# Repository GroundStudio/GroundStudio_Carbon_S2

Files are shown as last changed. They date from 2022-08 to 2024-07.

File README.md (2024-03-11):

GroundStudio Carbon S2
====================================
Carbon S2 cropat la 150 h (https://ardushop.ro/ro/home/2063-placa-de-dezvoltare-carbon-s2.html)

Get it from [ardushop.ro](https://ardushop.ro/ro/home/2063-placa-de-dezvoltare-carbon-s2.html)

Explore all the GroundStudio products at [GroundStudio.ro](https://groundstudio.ro/)

Description
-------------------
Features highly integrated ESP32-S2 with 2.4 GHz WiFi, 4MB Flash, 320kB SRAM, 128kB ROM, 18 GPIO, 10 ADC, 8 touch sensitive pins, 2 UART, I²C 3V3 adapter, RGB smart LED and 1 cell LiPo/LiIon battery charger with optional battery connector.

Contents
-------------------

* [/Documentation](https://github.com/GroundStudio/GroundStudio_Carbon_S2/tree/main/Documentation) -- Pinout.
* [/Hardware](https://github.com/GroundStudio/GroundStudio_Carbon_S2/tree/main/Hardware) -- Schematics, layout.

Versions
-------------------
*(Not all tags shown)*

* [REV0.0.2]
  * changed GPIO3 with GPIO12 between R3 and R8 because GPIO12 cannot be pulled high while in flash mode
  * added 100nF in parallel with R7 for better battery voltage level reading
  * modified the i2c connector label for better visibility
  * adjusted the position of the solder-jumper labels
  * increased the copper fill area under the uC for better cooling

License
-------------------

This is released under the [Attribution-ShareAlike 4.0 International (CC BY-SA 4.0)](https://creativecommons.org/licenses/by-sa/4.0/) license. 
**You are welcome to use this for commercial purposes.**

Please consider contributing back to this project or others to help the open-source hardware community continue to thrive and grow! 

Certifications:

[Open Source Hardware Association](https://certification.oshwa.org/ro000008.html)   
   
certification-mark-RO000008-wide (https://certification.oshwa.org/ro000008.html)

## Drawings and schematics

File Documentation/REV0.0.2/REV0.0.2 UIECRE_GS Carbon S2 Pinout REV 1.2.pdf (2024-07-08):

# GroundStudio Carbon S2

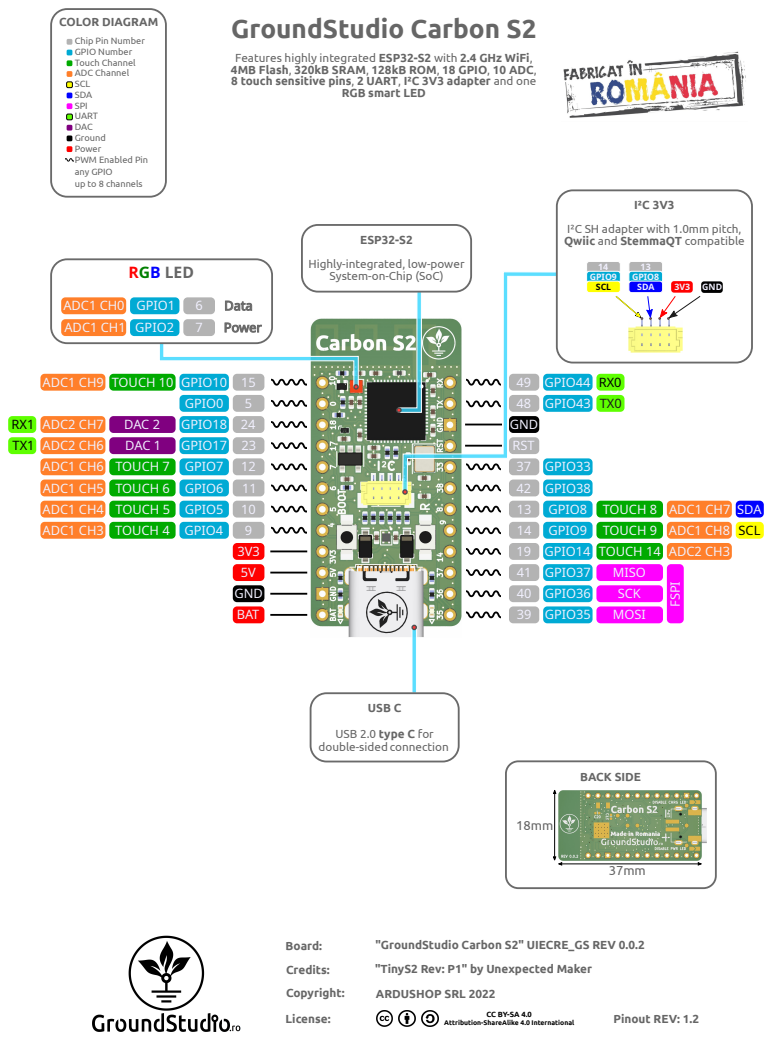
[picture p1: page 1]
COLOR DIAGRAM; ESP32-S2; BACK SIDE; I²C 3V3; GPIO9; GND; GPIO8; SCL; SDA; USB C; GND RST; GPIO38; GPIO8 GPIO9 GPIO14 GPIO37 GPIO36 GPIO35; MISO SCK MOSI; 37 GPIO33; 48 GPIO43; 49 GPIO44; TOUCH 8 TOUCH 9 TOUCH 14; ADC1 CH7 ADC1 CH8 ADC2 CH3; GND BAT; DAC 1 TOUCH 7 TOUCH 6 TOUCH 5; DAC 2; TOUCH 4; GPIO17 GPIO7 GPIO6 GPIO5; GPIO18; GPIO0; GPIO4; GPIO10; ADC2 CH7 ADC2 CH6 ADC1 CH6 ADC1 CH5 ADC1 CH4 ADC1 CH3; ADC1 CH9 TOUCH 10; RGB LED; Data Power; ADC1 CH0 GPIO1 6; ADC1 CH1 GPIO2; Copyright: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

Chip Pin Number
GPIO Number
Touch Channel
ADC Channel
SCL
SDA
SPI
UART
DAC
Ground
Power
PWM Enabled Pin
any GPIO
up to 8 channels

Features highly integrated ESP32-S2 with 2.4 GHz WiFi,
4MB Flash, 320kB SRAM, 128kB ROM, 18 GPIO, 10 ADC,
8 touch sensitive pins, 2 UART, I²C 3V3 adapter and one

RGB smart LED

I²C SH adapter with 1.0mm pitch,
Qwiic and StemmaQT compatible

Highly-integrated, low-power
System-on-Chip (SoC)

USB 2.0 type C for
double-sided connection

"GroundStudio Carbon S2" UIECRE_GS REV 0.0.2

Attribution-ShareAlike 4.0 International

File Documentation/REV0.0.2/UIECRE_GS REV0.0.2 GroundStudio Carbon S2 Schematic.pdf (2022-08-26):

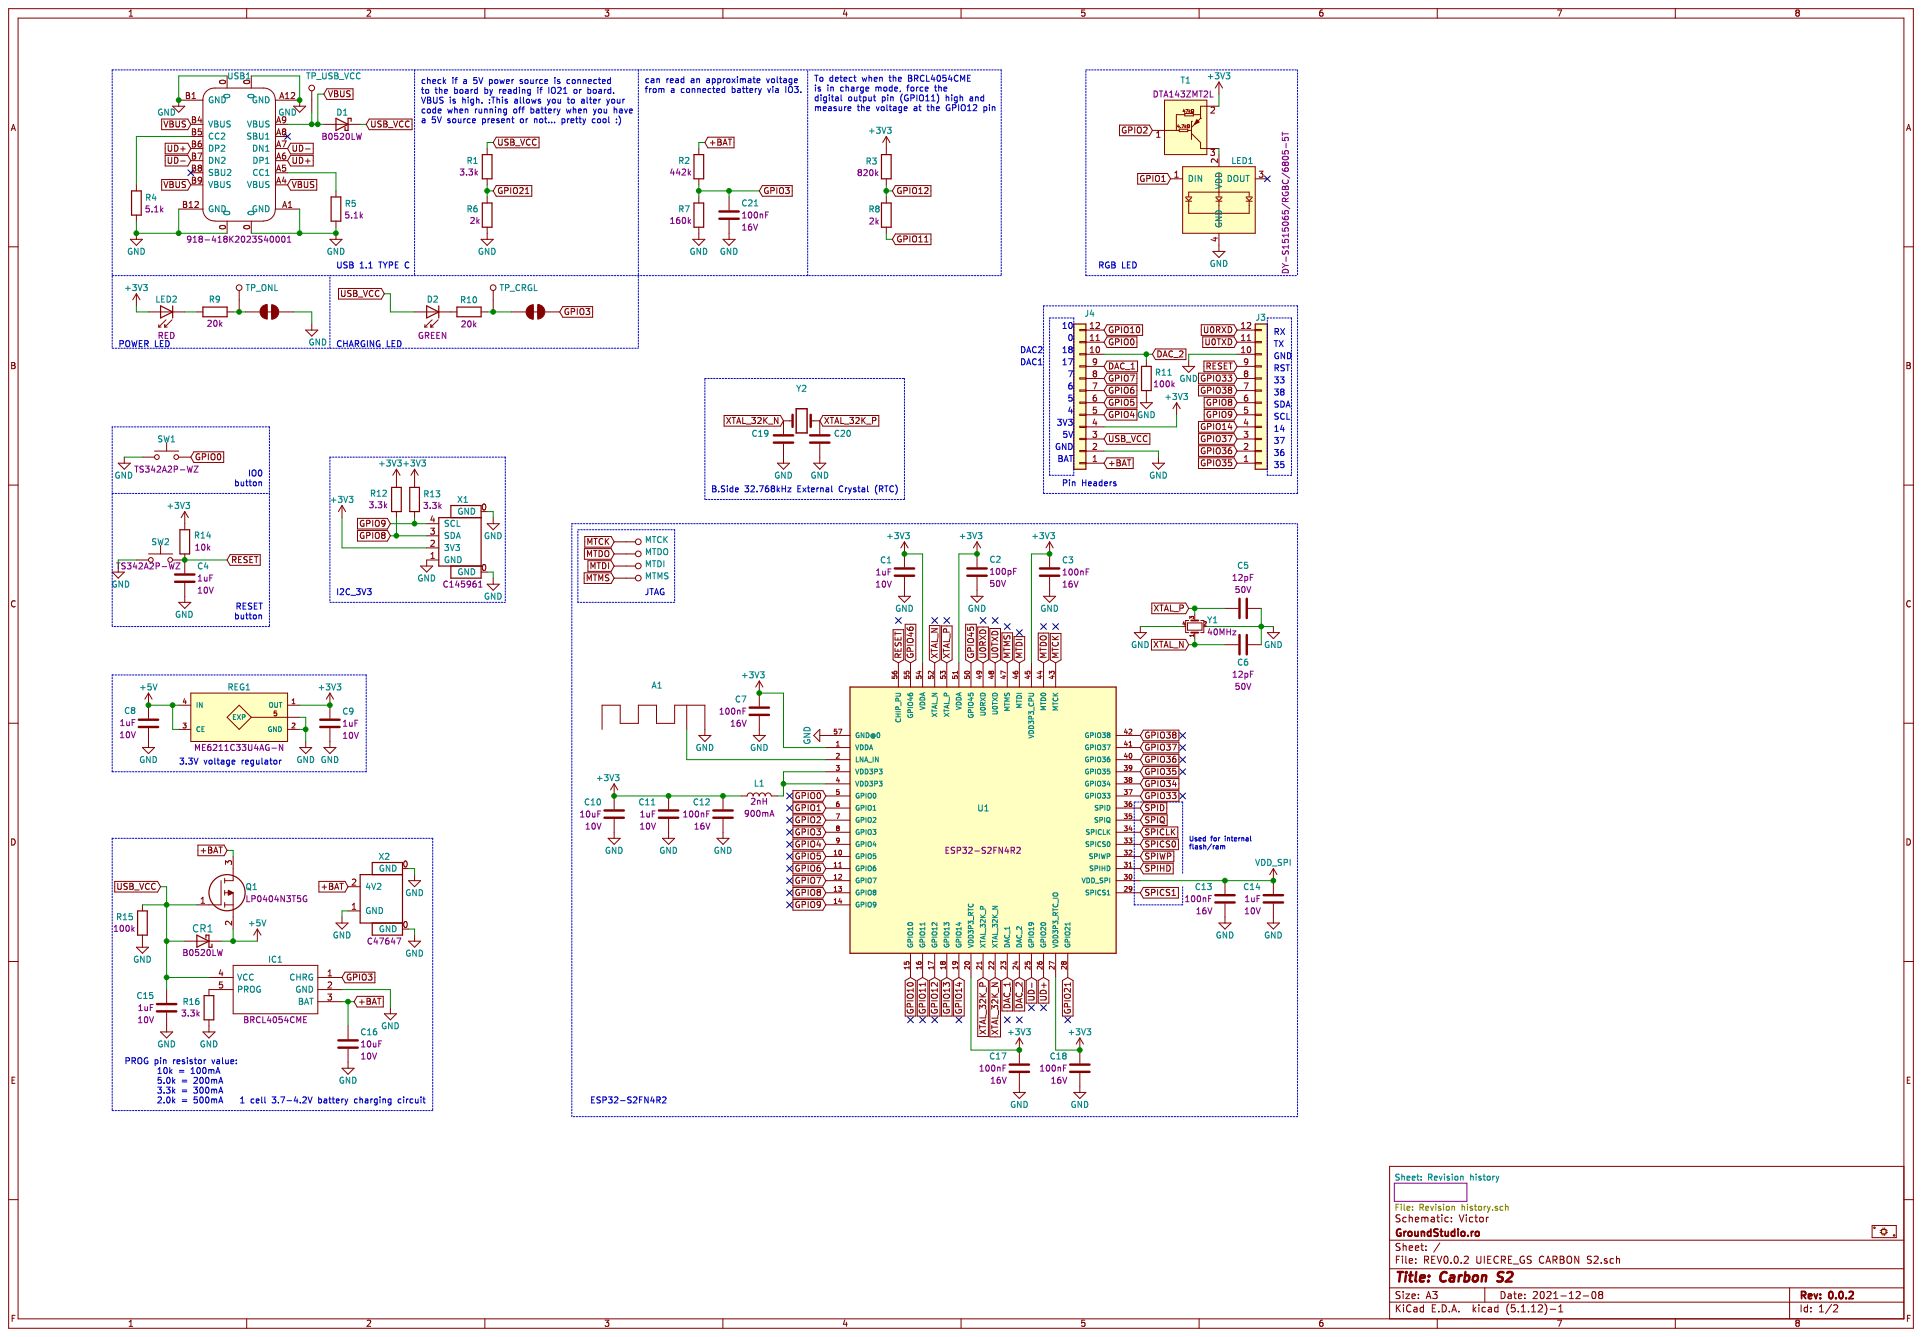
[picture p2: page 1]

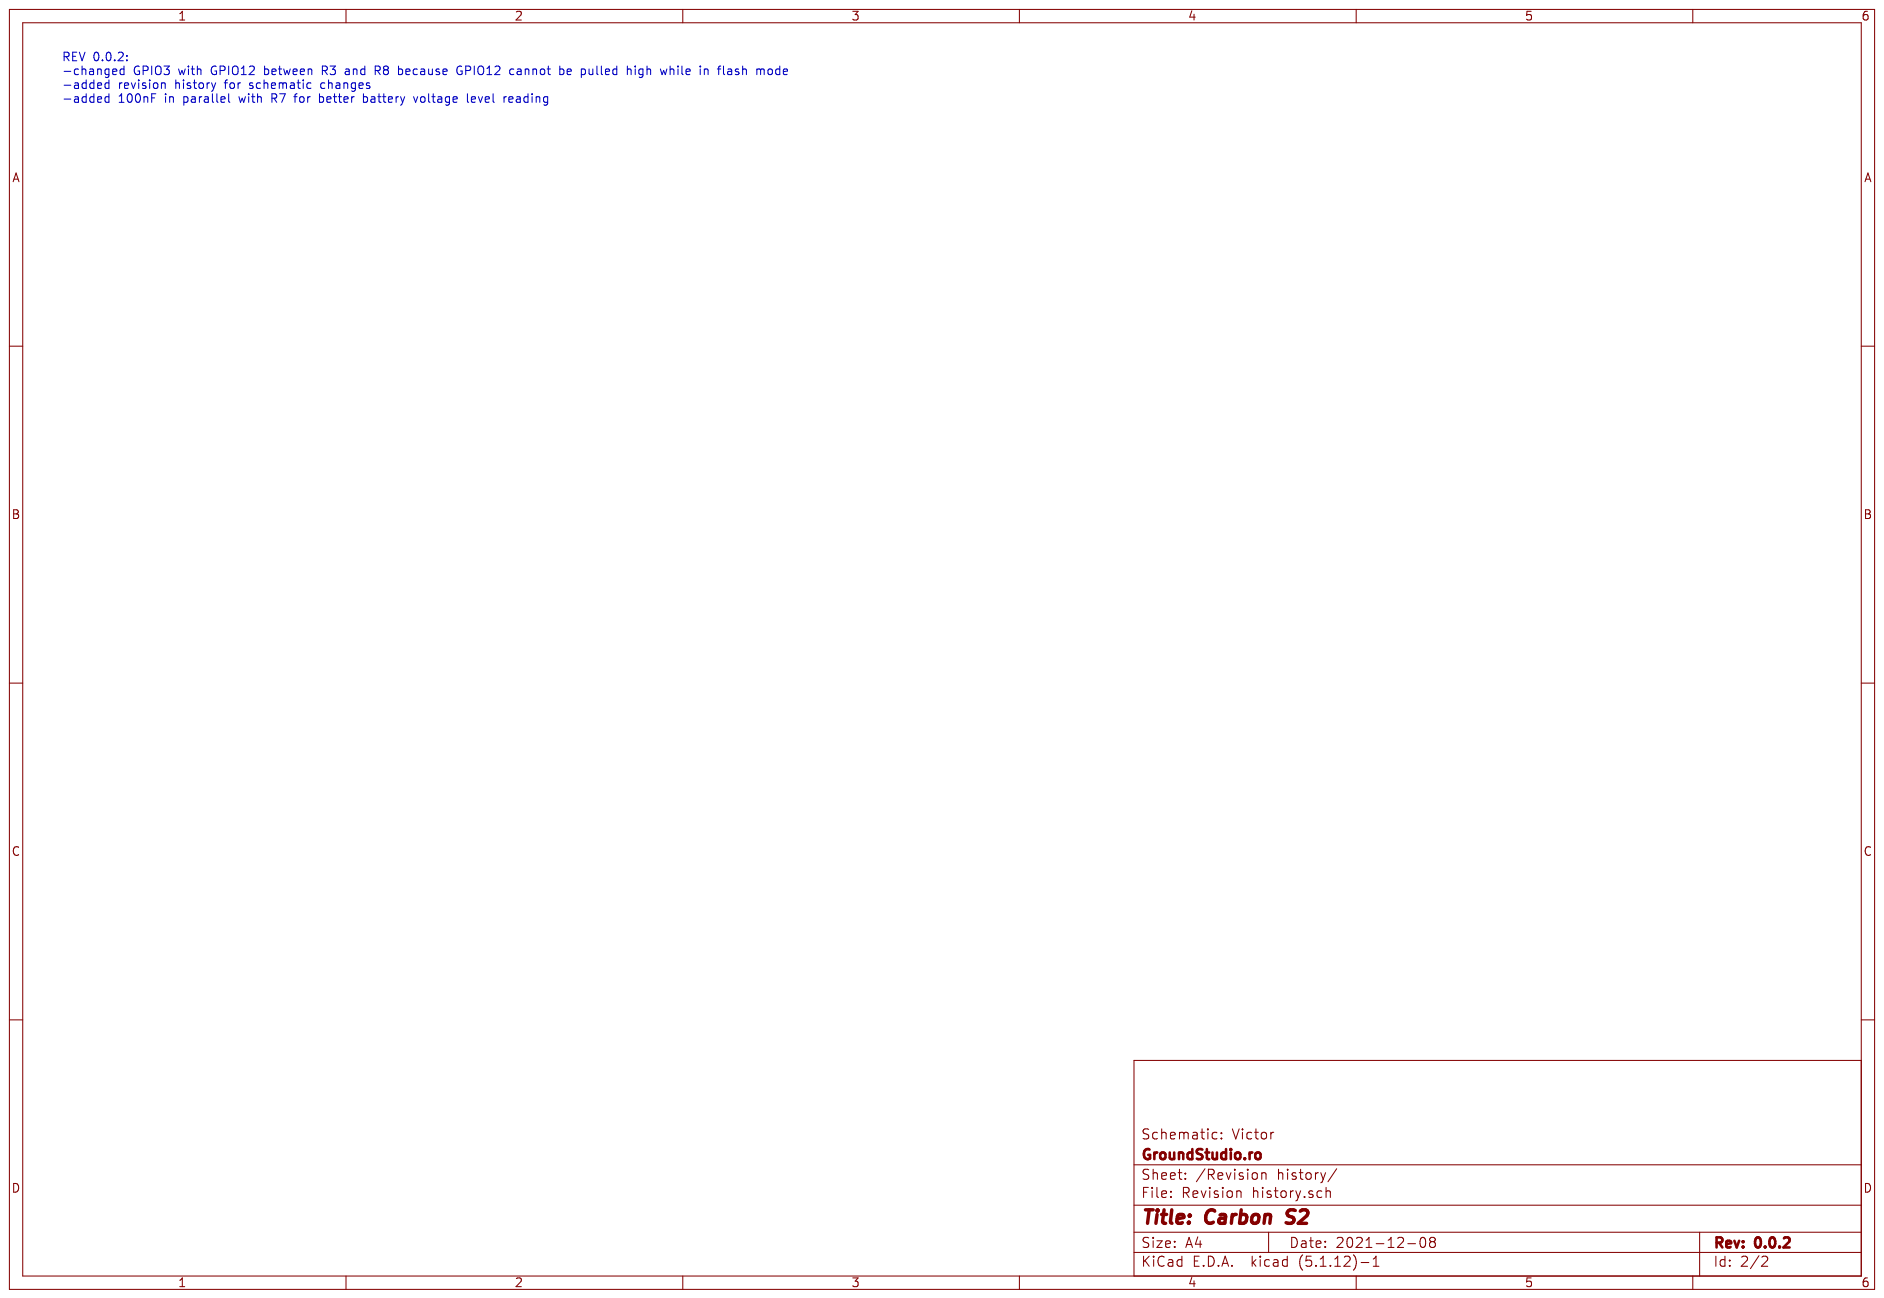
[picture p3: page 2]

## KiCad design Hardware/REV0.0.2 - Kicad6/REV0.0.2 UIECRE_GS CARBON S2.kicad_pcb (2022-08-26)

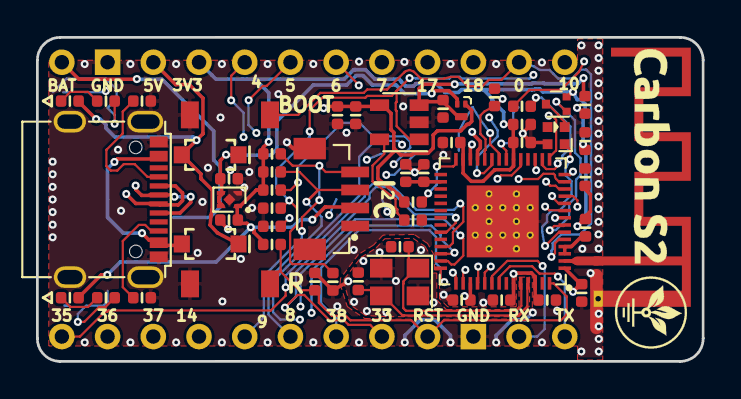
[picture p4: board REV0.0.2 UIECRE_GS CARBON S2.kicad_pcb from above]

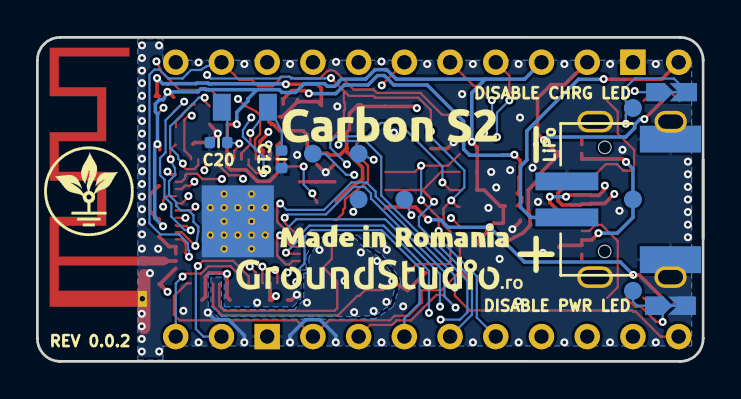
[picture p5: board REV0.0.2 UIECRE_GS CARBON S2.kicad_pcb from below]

Board: 4 copper layers, 37.0 x 18.0 mm, 67 parts (8 on the bottom side), 52 nets.

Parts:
A1: SWRA117D_2.4GHz; Texas_SWRA117D_2.4GHz_Left
C1, C4, C8, C9, C11, C14, C15: C_0402_1uF_10V; C_0402_alt
C2: C_0402_100pF_50V; C_0402_alt
C3, C7, C12, C13, C17, C18, C21: C_0402_100nF_16V; C_0402_alt
C5, C6: C_0402_12pF_50V; C_0402_alt
C10, C16: C_0402_10uF_10V; C_0402_alt
C19, C20: DNP C_0402_alt; C_0402_alt
CR1: SOD-123 B0520LW; SOD-123
D1: SOD-123 B0520LW; SOD-123
D2: LED_0402_GREEN; LED_0402_alt
IC1: SOT23-5 BRCL4054CME; SOT-23-5
J1: PWR LED DISABLE; SolderJumper_NC
J2: CHARGING LED DISABLE; SolderJumper_NC
J3, J4: PinHeader_1x12_P2.54_V_M A2541WV-12P; PinHeader_1x12_P2.54mm_Vertical_Male
L1: L_0402_2nH_900mA; L_0402_alt
LED1: SK6805-EC15 DY-S1515065; SK6805-EC15
LED2: LED_0402_RED; LED_0402_alt
Q1: SOT-883 LP0404N3T5G; SOT-883
R1, R12, R13, R16: R_0402_3.3k; R_0402_alt
R2: R_0402_442k; R_0402_alt
R3: R_0402_820k; R_0402_alt
R4, R5: R_0402_5.1k; R_0402_alt
R6, R8: R_0402_2k; R_0402_alt
R7: R_0402_160k; R_0402_alt
R9, R10: R_0402_20k; R_0402_alt
R11, R15: R_0402_100k; R_0402_alt
R14: R_0402_10k; R_0402_alt
REG1: FBP1-1-4_ME6211C33U4AG-N; FBP1-1-4
SW1, SW2: TS342A2P-WZ
T1: SOT-723 DTA143ZMT2L; SOT-723
TP1: TP_USB_VCC; TestPoint
TP2: TP_ONL; TestPoint
TP3: TP_CRGL; TestPoint
TP4: MTCK; TestPoint
TP5: MTDO; TestPoint
TP6: MTDI; TestPoint
TP7: MTMS; TestPoint
U1: QFN-56-1EP_7x7mm ESP32-S2FN4R2; QFN-56-1EP_7x7mm_P0.4mm_EP4x4mm
USB1: USB_C 918-418K2023S40001; USB_C_C167321
X1: SH__1x04_Vertical C145961; SH__1x04_P1.00mm_Vertical
X2: PH__1x02_P2.00mm_Horizontal C47647; PH__1x02_P2.00mm_Horizontal
Y1: Crystal_SMD_3225-4P JF4040M; Crystal_SMD_3225-4Pin_3.2x2.5mm
Y2: DNP Crystal_32.768kHz_SMD; Crystal_32.768kHz_SMD

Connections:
+3V3: C1.1, C2.2, C3.1, C7.1, C9.1, C10.1, C11.1, C12.1, C17.1, C18.1, J4.4, L1.1, LED2.2, R3.1, R12.2, R13.1, R14.2, REG1.1, T1.2, U1.1, U1.20, U1.27, U1.45, U1.51, U1.54, X1.2
+5V: C8.2, CR1.1, Q1.2, REG1.3, REG1.4
+BAT: C16.1, IC1.3, J4.1, Q1.3, R2.2, X2.2
DAC_1: J4.9, U1.23
DAC_2: J4.10, R11.2, U1.24
Feed: A1.1, U1.2
GND: A1.2, C1.2, C2.1, C3.2, C4.2, C5.2, C6.1, C7.2, C8.1, C9.2, C10.2, C11.2, C12.2, C13.2, C14.2, C15.2, C16.2, C17.2, C18.2, C19.2, C20.2, C21.2, IC1.2, J1.2, J3.10, J4.2, LED1.4, R4.2, R5.2, R6.1, R7.1, R11.1, R15.1, R16.1, REG1.2, REG1.5, SW1.1, SW2.1, U1.57, USB1.0, USB1.A1, USB1.A12, USB1.B1, USB1.B12, X1.0, X1.1, X2.0, X2.1, Y1.2, Y1.4
GPIO0: J4.11, SW1.2, U1.5
GPIO1: LED1.1, U1.6
GPIO2: T1.1, U1.7
GPIO3: C21.1, IC1.1, J2.1, R2.1, R7.2, U1.8
GPIO4: J4.5, U1.9
GPIO5: J4.6, U1.10
GPIO6: J4.7, U1.11
GPIO7: J4.8, U1.12
GPIO8: J3.6, R12.1, U1.13, X1.3
GPIO9: J3.5, R13.2, U1.14, X1.4
GPIO10: J4.12, U1.15
GPIO11: R8.2, U1.16
GPIO12: R3.2, R8.1, U1.17
GPIO14: J3.4, U1.19
GPIO21: R1.1, R6.2, U1.28
GPIO33: J3.8, U1.37
GPIO35: J3.1, U1.39
GPIO36: J3.2, U1.40
GPIO37: J3.3, U1.41
GPIO38: J3.7, U1.42
MTCK: TP4.~, U1.43
MTDI: TP6.~, U1.46
MTDO: TP5.~, U1.44
MTMS: TP7.~, U1.47
unnamed: D2.1, R10.1
unnamed: IC1.5, R16.2
unnamed: J1.1, R9.2, TP2.~
unnamed: J2.2, R10.2, TP3.~
unnamed: L1.2, U1.3, U1.4
unnamed: LED1.2, T1.3
unnamed: LED2.1, R9.1
unnamed: R4.1, USB1.B5
unnamed: R5.1, USB1.A5
RESET: C4.1, J3.9, R14.1, SW2.2, U1.56
U0RXD: J3.12, U1.49
U0TXD: J3.11, U1.48
UD+: U1.26, USB1.A6, USB1.B6
UD-: U1.25, USB1.A7, USB1.B7
USB_VCC: C15.1, CR1.2, D1.1, D2.2, IC1.4, J4.3, Q1.1, R1.2, R15.2
VBUS: D1.2, TP1.~, USB1.A4, USB1.A9, USB1.B4, USB1.B9
VDD_SPI: C13.1, C14.1, U1.30
XTAL_32K_N: C19.1, U1.22, Y2.1
XTAL_32K_P: C20.1, U1.21, Y2.2
XTAL_N: C6.2, U1.52, Y1.1
XTAL_P: C5.1, U1.53, Y1.3

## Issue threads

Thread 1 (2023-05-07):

what board should I use for platformio?

dutchsnowden, 2023-05-07:
If I want to develop in Platformio, what board should I use?

victor1115, 2023-09-08:
We can only help to get you started on Arduino IDE for wich you can find some setup example to control the onboard RGB led in the development board page:

https://ardushop.ro/ro/home/2063-placa-de-dezvoltare-carbon-s2.html

For the moment we do not have enough resources to provide support for the Platformio environment.

Closed 2023-09-08.

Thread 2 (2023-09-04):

Need to use this with ESPHome

Arise, 2023-09-04:
What should I use under esp32 > board in the yaml file?

example:
```
# Example configuration entry
esp32:
  board: nodemcu-32s
  framework:
    type: arduino
    version: 2.0.0
```

victor1115, 2023-09-08:
In Arduino IDE we use this as board: **ESP32S2 Dev Module**
The microcontroller used on the GroundStudio Carbon S2 board is this one: **ESP32-S2FN4R2**
It has 4MB FLASH and 2MB PSRAM.
At the moment we do not provide support for the ESPHome system.

Closed 2023-09-08.

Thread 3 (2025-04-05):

New User. Tips for Using Carbon S2?

u31899, 2025-04-05:
Hi there,

I am fairly new to using microcontrollers, having only used arduinos and raspberry pi's prior. I purchased a couple of your Carbon S2 boards with the hopes of better understanding of the ESP 32 system, and a cheaper alternative to arduino boards for the various projects I have been working on.

Out of the box, the Carbon S2 seems to be running a program that fades the rgb led through various colors. I thought I would try and write my own program to see if I can get it doing the same, however I am having issues with it not working. I am programming via the Arduino IDE with the ESP32 board extension installed. This allows me to upload programs to the Carbon S2, but I have had no luck getting anything to run. It is clear that I wrote something to the device, as the LED is dark, as such it is not running through its preloaded program.

Would you have any example code for your program that I could reference? In addition to that, do you have any resources on using your board, or boards similar to it?

Thanks for your help.

Best,

Matt

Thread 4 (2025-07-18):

Questions regarding Carbon S2 charging pins

tomtempest, 2025-07-18:
From the schematic, I try to understand the reading of the charging pins:

USB is connected – GPIO21 - that works as expected
Approximate battery voltage at GPIO3 – unreliable numbers from 0 to 8191 – if I connect a battery stays at 0

GPIO3 would be fine, if I had realiable values – but 0 value with and without a battery – I can’t use.

Detect charge mode:  output GPIO11 to HIGH, GPIO12 as analog input  - value is always 8191.

I think GPIO12 does not work, because the battery is connected to another board with a voltage regulator that also powers the S2 chip at 3.3V.
It is necessary, because it also drives vibration devices through DRV2605 parts.

Could I change the external wiring to make it work?

Please comment on the issues and if you do have sample code please share it.

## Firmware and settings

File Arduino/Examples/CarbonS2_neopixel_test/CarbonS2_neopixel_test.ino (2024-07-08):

// A basic everyday NeoPixel strip test program.

// NEOPIXEL BEST PRACTICES for most reliable operation:
// - Add 1000 uF CAPACITOR between NeoPixel strip's + and - connections.
// - MINIMIZE WIRING LENGTH between microcontroller board and first pixel.
// - NeoPixel strip's DATA-IN should pass through a 300-500 OHM RESISTOR.
// - AVOID connecting NeoPixels on a LIVE CIRCUIT. If you must, ALWAYS
//   connect GROUND (-) first, then +, then data.
// - When using a 3.3V microcontroller with a 5V-powered NeoPixel strip,
//   a LOGIC-LEVEL CONVERTER on the data line is STRONGLY RECOMMENDED.
// (Skipping these may work OK on your workbench but can fail in the field)

#include <Adafruit_NeoPixel.h>
#ifdef __AVR__
 #include <avr/power.h> // Required for 16 MHz Adafruit Trinket
#endif

// Which pin on the Arduino is connected to the NeoPixels?
// On a Trinket or Gemma we suggest changing this to 1:
#define LED_PIN    1
#define LED_ENABLE_PIN 2

// How many NeoPixels are attached to the Arduino?
#define LED_COUNT 1

// Declare our NeoPixel strip object:
Adafruit_NeoPixel strip(LED_COUNT, LED_PIN, NEO_GRB + NEO_KHZ800);
// Argument 1 = Number of pixels in NeoPixel strip
// Argument 2 = Arduino pin number (most are valid)
// Argument 3 = Pixel type flags, add together as needed:
//   NEO_KHZ800  800 KHz bitstream (most NeoPixel products w/WS2812 LEDs)
//   NEO_KHZ400  400 KHz (classic 'v1' (not v2) FLORA pixels, WS2811 drivers)
//   NEO_GRB     Pixels are wired for GRB bitstream (most NeoPixel products)
//   NEO_RGB     Pixels are wired for RGB bitstream (v1 FLORA pixels, not v2)
//   NEO_RGBW    Pixels are wired for RGBW bitstream (NeoPixel RGBW products)


// setup() function -- runs once at startup --------------------------------

void setup() {
  pinMode(LED_ENABLE_PIN, OUTPUT);
  digitalWrite(LED_ENABLE_PIN, 0);
  // These lines are specifically to support the Adafruit Trinket 5V 16 MHz.
  // Any other board, you can remove this part (but no harm leaving it):
#if defined(__AVR_ATtiny85__) && (F_CPU == 16000000)
  clock_prescale_set(clock_div_1);
#endif
  // END of Trinket-specific code.

  strip.begin();           // INITIALIZE NeoPixel strip object (REQUIRED)
  strip.show();            // Turn OFF all pixels ASAP
  strip.setBrightness(50); // Set BRIGHTNESS to about 1/5 (max = 255)
  colorWipe(strip.Color(255,   0,   0), 500); // Red
  Serial.begin(115200);
  while(!Serial);
  Serial.println("Setup");
}


// loop() function -- runs repeatedly as long as board is on ---------------

void loop() {
  Serial.println("Loop start");

  // Fill along the length of the strip in various colors...
  Serial.println("Color Wipe Red");
  colorWipe(strip.Color(255,   0,   0), 500); // Red
  Serial.println("Color Wipe Green");
  colorWipe(strip.Color(  0, 255,   0), 500); // Green
  Serial.println("Color Wipe Blue");
  colorWipe(strip.Color(  0,   0, 255), 500); // Blue

  // Do a theater marquee effect in various colors...
  Serial.println("White, half brightness");
  theaterChase(strip.Color(127, 127, 127), 10); // White, half brightness
  Serial.println("Red, half brightness");
  theaterChase(strip.Color(127,   0,   0), 10); // Red, half brightness
  Serial.println("Blue, half brightness"); 
  theaterChase(strip.Color(  0,   0, 127), 10); // Blue, half brightness

  Serial.println("Flowing rainbow cycle along the whole strip");
  rainbow(1);             // Flowing rainbow cycle along the whole strip
  // theaterChaseRainbow(50); // Rainbow-enhanced theaterChase variant
}


// Some functions of our own for creating animated effects -----------------

// Fill strip pixels one after another with a color. Strip is NOT cleared
// first; anything there will be covered pixel by pixel. Pass in color
// (as a single 'packed' 32-bit value, which you can get by calling
// strip.Color(red, green, blue) as shown in the loop() function above),
// and a delay time (in milliseconds) between pixels.
void colorWipe(uint32_t color, int wait) {
  for(int i=0; i<strip.numPixels(); i++) { // For each pixel in strip...
    strip.setPixelColor(i, color);         //  Set pixel's color (in RAM)
    strip.show();                          //  Update strip to match
    delay(wait);                           //  Pause for a moment
  }
}

// Theater-marquee-style chasing lights. Pass in a color (32-bit value,
// a la strip.Color(r,g,b) as mentioned above), and a delay time (in ms)
// between frames.
void theaterChase(uint32_t color, int wait) {
  for(int a=0; a<10; a++) {  // Repeat 10 times...
    for(int b=0; b<3; b++) { //  'b' counts from 0 to 2...
      strip.clear();         //   Set all pixels in RAM to 0 (off)
      // 'c' counts up from 'b' to end of strip in steps of 3...
      for(int c=b; c<strip.numPixels(); c += 3) {
        strip.setPixelColor(c, color); // Set pixel 'c' to value 'color'
      }
      strip.show(); // Update strip with new contents
      delay(wait);  // Pause for a moment
    }
  }
}

// Rainbow cycle along whole strip. Pass delay time (in ms) between frames.
void rainbow(int wait) {
  // Hue of first pixel runs 5 complete loops through the color wheel.
  // Color wheel has a range of 65536 but it's OK if we roll over, so
  // just count from 0 to 5*65536. Adding 256 to firstPixelHue each time
  // means we'll make 5*65536/256 = 1280 passes through this outer loop:
  for(long firstPixelHue = 0; firstPixelHue < 5*65536; firstPixelHue += 256) {
    for(int i=0; i<strip.numPixels(); i++) { // For each pixel in strip...
      // Offset pixel hue by an amount to make one full revolution of the
      // color wheel (range of 65536) along the length of the strip
      // (strip.numPixels() steps):
      int pixelHue = firstPixelHue + (i * 65536L / strip.numPixels());
      // strip.ColorHSV() can take 1 or 3 arguments: a hue (0 to 65535) or
      // optionally add saturation and value (brightness) (each 0 to 255).
      // Here we're using just the single-argument hue variant. The result
      // is passed through strip.gamma32() to provide 'truer' colors
      // before assigning to each pixel:
      strip.setPixelColor(i, strip.gamma32(strip.ColorHSV(pixelHue)));
    }
    strip.show(); // Update strip with new contents
    delay(wait);  // Pause for a moment
  }
}

// Rainbow-enhanced theater marquee. Pass delay time (in ms) between frames.
void theaterChaseRainbow(int wait) {
  int firstPixelHue = 0;     // First pixel starts at red (hue 0)
  for(int a=0; a<30; a++) {  // Repeat 30 times...
    for(int b=0; b<3; b++) { //  'b' counts from 0 to 2...
      strip.clear();         //   Set all pixels in RAM to 0 (off)
      // 'c' counts up from 'b' to end of strip in increments of 3...
      for(int c=b; c<strip.numPixels(); c += 3) {
        // hue of pixel 'c' is offset by an amount to make one full
        // revolution of the color wheel (range 65536) along the length
        // of the strip (strip.numPixels() steps):
        int      hue   = firstPixelHue + c * 65536L / strip.numPixels();
        uint32_t color = strip.gamma32(strip.ColorHSV(hue)); // hue -> RGB
        strip.setPixelColor(c, color); // Set pixel 'c' to value 'color'
      }
      strip.show();                // Update strip with new contents
      delay(wait);                 // Pause for a moment
      firstPixelHue += 65536 / 90; // One cycle of color wheel over 90 frames
    }
  }
}

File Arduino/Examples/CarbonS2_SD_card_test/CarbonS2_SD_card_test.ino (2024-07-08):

#include "FS.h"
#include "SD.h"
#include "SPI.h"

SPIClass spiSD;

#define SD_CS 14

void writeFile(fs::FS &fs, const char * path, const char * message){
    Serial.printf("Writing file: %s\n", path);

    File file = fs.open(path, FILE_WRITE);
    if(!file){
        Serial.println("Failed to open file for writing");
        return;
    }
    if(file.print(message)){
        Serial.println("File written");
    } else {
        Serial.println("Write failed");
    }
    file.close();
}

void setup()
{
  Serial.begin(9600);
  while (!Serial) delay(100);
  Serial.println();
  SPI.end(); 
  spiSD.begin(36, 37, 35, SD_CS); //CLK,MISO,MOSI,SS
  if (!SD.begin(SD_CS, spiSD))
  {
    Serial.println("Card Mount Failed");
    return;
  }
  else
  {
    Serial.println("Card Mount Successful");
  }

  uint8_t cardType = SD.cardType();

  Serial.print("SD Card Type: ");
  if(cardType == CARD_MMC){
        Serial.println("MMC");
    } else if(cardType == CARD_SD){
        Serial.println("SDSC");
    } else if(cardType == CARD_SDHC){
        Serial.println("SDHC");
    } else {
        Serial.println("UNKNOWN");
    }

    uint64_t cardSize = SD.cardSize() / (1024 * 1024);
    Serial.printf("SD Card Size: %lluMB\n", cardSize);
    
  writeFile(SD, "/hello S2.txt", "Hello S2");
  Serial.printf("Total space: %lluMB\n", SD.totalBytes() / (1024 * 1024));
  Serial.printf("Used space: %lluMB\n", SD.usedBytes() / (1024 * 1024));
}

void loop()
{ }

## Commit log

2022-08-26 - initial commit
    [REV0.0.2 UIECRE_GS CARBON S2.kicad_pcb, REV0.0.2 UIECRE_GS CARBON S2.kicad_sch, Revision history.kicad_sch]
2022-08-26 - added schematic pdf file
2023-10-26 - added .step 3D file of the board
2024-07-08 - added 2 arduino code examples
2024-07-08 - updated pinout and datasheet (SPI pins)
